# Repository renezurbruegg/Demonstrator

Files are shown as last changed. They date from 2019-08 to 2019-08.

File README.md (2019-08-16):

# PULPETUM MOBILE

## INSTALL INSTRUCTIONS
#### Set up Raspberry pi using NOOBS

Download NOOBS and boot Raspberry Pi

[Instructions](https://www.raspberrypi.org/downloads/noobs/)

Set up the operating system using Monitor and Keyboard. 

### Enable ssh
[See](https://www.raspberrypi.org/documentation/remote-access/ssh/)

#### Connect 
Get the Ip adress of the raspberry pi. Make sure the raspberry pi is in the same network as your computer
```bash
    ifconfig
```
Connect to the raspberry pi using ssh
 ```bash
    ssh pi@<your pi IP>
```
#### Enable I2c
```bash
    sudo raspi-config
```
#### install I2C utilities
```bash
    sudo apt-get install python-smbus i2c-tools
```

#### Restart Pi
```bash
    sudo reboot
```

#### `[ Optional `] Installing rmate for remote file editing
To edit files locally on your PC you need to set up rmate. 
Otherwise all editing of the files has to be done over ssh using console line editor like nano or vim.

1. Install rmate client on raspberry pi.
    ```bash
        pip install install rmate
    ```
2. Install an editor locally to edit the files. Must support the rmate plugin.
    e.g. Install [Visual Studio Code](https://code.visualstudio.com/download), install [Rmate Plugin](https://marketplace.visualstudio.com/items?itemName=rafaelmaiolla.remote-vscode), follow instruction from the plugin (https://medium.com/@prtdomingo/editing-files-in-your-linux-virtual-machine-made-a-lot-easier-with-remote-vscode-6bb98d0639a4) and start local server. 

3. Connect back to the Raspberry pi
    ```bash
        ssh -R 52698:127.0.0.1:52698 pi@<Raspberry Pi IP>
    ```
4. To edit e file remotely enter:
    ```bash
    rmate "yourFile.py"
    ```

#### Setting up the flask Backend Server
---

1.  Clone the repo 

    ```bash
    git clone --depth 1 https://gitlab.ethz.ch/zrene/pulp-demonstrator.git
    cd pulp-demonstrator
    ```

2.  Install the backend related requirements
    ```bash
    cd Server
    cd backend
    sudo pip install -r requirements.txt
    ```
#### Setting up the Angular Frontend Server
---
1.  Install frontend related dependencies

    -   Easiest way to handle node related dependencies is to install [nvm](https://github.com/creationix/nvm)
    -   Once you have node installed, install the project's dependencies

    ```bash
    cd ..
    cd front

    # install global dependencies
    npm install typescript -g

    # install project related dependencies
    npm install

    # run server
    ng serve --host 0.0.0.0
    ```

4.  Now navigate to `http://<Your RPI IP>:4200`

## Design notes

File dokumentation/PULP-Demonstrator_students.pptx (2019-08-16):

## PULP Demonstrator

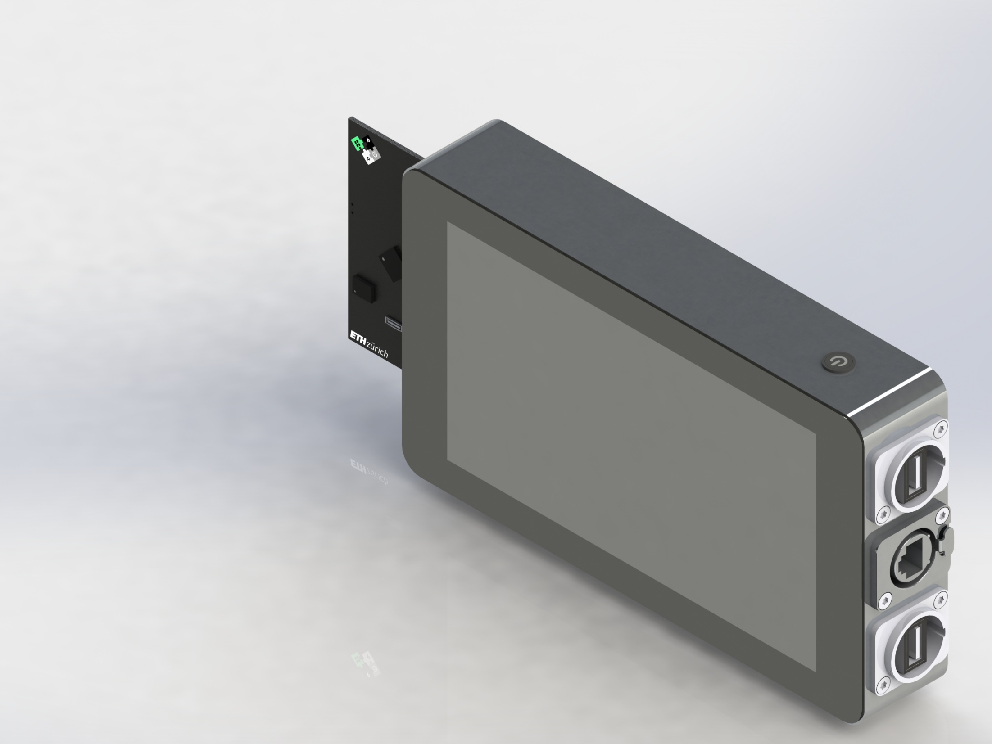
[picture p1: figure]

## PULP Demonstrator – Block Diagram

Philipp Mayer

Our ICs typically do not have a nonvolatile memory -> you have to supply them, flash your program and keep them supplied. To do so the connector needs the signal for a JTAG interface and in the housing must be space for this programmer + USB connection
https://www.olimex.com/Products/ARM/JTAG/ARM-USB-OCD-H/

## PULP Demonstrator – Block Diagram

Somewhere must be a button to turn off the whole thing

## PULP Demonstrator – Block Diagram

We need:
- USB to supply/charge the demonstrator
- A way to transfer easy data to and from the demonstrator (USB + Ethernet)
- Nice would be to design the housing in a way that Bluetooth and WiFi is still working

## PULP Demonstrator – Block Diagram

Connector selection:
- The connection to the daughter board must be mechanical stable
- Ideally it’s a common standard
- In the pin definition 1.) keep enough GND pins 2.) separate digital from analog 3.) keep unused pins for future usage

## Connector Selection

Ideal would be a widely used box connector with 2.54mm pitch (unfortunately a female solder connector is not easy to find):
https://www.te.com/deu-de/product-1-5103311-0.html (https://www.te.com/deu-de/product-1734099-6.html)
Alternative is something in this direction. Or direct in card format without (https://www.te.com/deu-de/product-1734099-6.html) connector on daughter board side
https://www.te.com/deu-de/product-1734099-6.html
https://www.te.com/deu-de/product-1734098-6.html

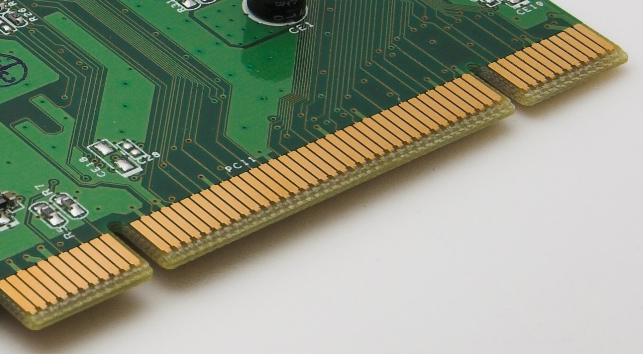
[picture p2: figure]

## PULP Demonstrator – Block Diagram

This connection must not be rigid. You can use cables to design a thinner device

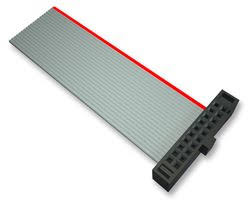
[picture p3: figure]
Bildergebnis für flachbandkabel

## PULP Demonstrator – Block Diagram

Building a PULP daughter board is not necessary part of your thesis. This we decide depending on your progress. However we need a way to test your HW and show the performance -> At least a simple daughter board with this banana/lab connecters should be made

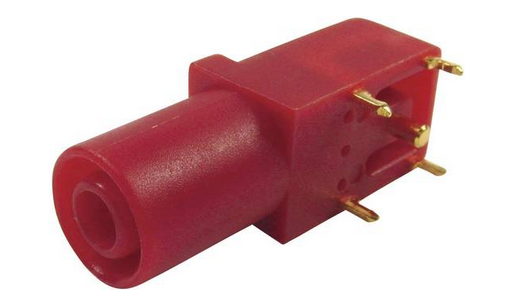
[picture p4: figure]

## Your PCB

The power supply is not simple as you need multiple voltage levels including a decoupled and stable supply for the analog measurement part.

Common practice is a switching regulator (efficiency) followed by a LDO (stability). If you read the documentation of the TI sample project you will find a good explanation.

There is also a charge pump to get a dual supply for the body biasing circuit

## Your PCB

Our ICs have typically a own supply for IOs. Never the less its not always 3.3V of the Rpi
-> all signals need level shifter.
The voltage level for the daughter board must come as input from the board

1.2 –> 3.3V

V(VGPIO)

3.3V

## Your PCB

The PCAL6416 has a I2C voltage and a IO voltage.
as the TPS62740 will have 5V input voltage also the control pins should have 5V levels

The same is valid for the I2C signals. Here you will need multiple pull-up resistors to the right voltage level

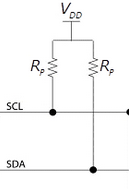
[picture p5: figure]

5V

3.3V

3.3V

V(VGPIO)

## Your PCB

I would recommend to take the analog input form this project:
TI Designs:TIDA-01012
Wireless IoT, Bluetooth® LowEnergy,4½ Digit,
100-kHzTrueRMSDigitalMultimeterReferenceDesign
It explains very nice the important parts, including design guide etc…
You will learn a lot by reading and partly replicating it.
(There are also more complex 24Bit examples but i think this will be sufficient)
There are two options:
a.) using a multiplexer to have different channels
b.) just build this part multiple times on your PCB
(The second will bring better results and is easier but will limit the number of channels )

## Which Component Packages?

It’s easy to design boards which are almost impossible to solder (especially without practice)
Depending on the availability (you will not get 100uF in a 0402 package) 0603 or 0402 is nice to solder -> we have also most resistors here
For ICs the best compromise between parasitics, soldering and size is QFN
-> I try to avoid packages with legs (however for opamps etc. this is not always possible. Its also a matter of taste.
-> We can solder BGAs, but typically they make the PCB more expensive (more layers lower pitch)

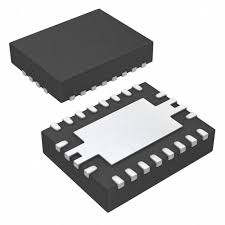
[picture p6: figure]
Bildergebnis für QFN
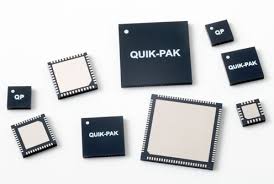
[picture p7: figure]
Bildergebnis für QFN
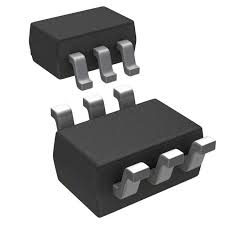
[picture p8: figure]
Bildergebnis für sc70
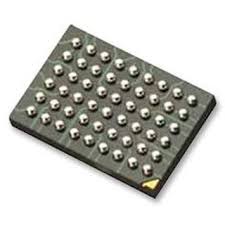
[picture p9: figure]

## Software design

1.) setup linux
2.) play with kivy (if you don’t find a better alternative)
3.) connect a LTC2631(on a breakout board) and write the I2C driver
3.) if it is possible to the same for the other I2C ICs
4.) write the driver to SPI ADC
5.) make a fully working demo
- Find a user-friendly way to configure the voltages
- It should be a demonstrator -> the configuration must be somehow password controlled
- Find ways to visualize your data
6.) If the basics work perfect think about how to support different daughter boards. How configurations can be stored. How new GUIs can be implemented
7.) The ultimate application for now is to get a video stream via SPI. Would you be able to read this data and show it on the LCD?

SW design should be independent from the HW design process!

## Mechanical design

-> be aware that the workshop will need time
1.) think about the best suited way to fit everything inside.
2.) find connectors, buttons etc. How can be everything accessible without big afford.
4.) Define together with HW board size, connector type, and connector position.
5.) Design a case under consideration of all information. Draw all important parts. (for most connectors etc. 3D files will be available. In Altium you can make a quick export without having the layout finished)
6.) During the drawing think about how the machine will manufacture it. Not everything is possible (min radii, machining direction, complexity of your design.. )
7.) Meeting with the workshop -> (adaption?) -> 3D printing
8.) if everything is perfect manufacturing in alu.

Case design should be as much independent as possible from the HW

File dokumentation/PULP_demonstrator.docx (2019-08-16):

# 1 Connectors

## 1.1 Sense & Supply Module <-> Raspberry Pi 3

Sense & Supply Module ist am auf der linken Seite des Gehäuses und der Rasperry Pi auf der rechten Seite (direkter Anschluss für USB, Ethernet). Beide Boards warden durch ein 40 Pin Flachbandkabel verbunden. (Achtung 50pin stecker) https://www.te.com/deu-de/product-1-5103311-0.html

https://www.raspberrypi.org/documentation/usage/gpio/README.md

Pinseite Bohrloch

1 | 3.3V | 5V | 2
3 | GPIO2 (Data) | 5V | 4
5 | GPIO3 (Clock) | GND | 6
7 | GPIO4 | GPIO14 (TX) | 8
9 | GND | GPIO15 (RX) | 10
11 | GPIO17 | GPIO18 | 12
13 | GPIO27 | GND | 14
15 | GPIO22 | GPIO23 | 16
17 | 3.3V | GPIO24 | 18
19 | GPIO10 (MOSI) | GND | 20
21 | GPIO9 (MISO) | GPIO25 | 22
23 | GPIO11 (SCLK) | GPIO8 (CE0) | 24
25 | GND | GPIO7 (CE1) | 26
27 | ID EEPROM | ID EEPROM | 28
29 | GPIO5 | GND | 30
31 | GPIO6 | GPIO12 | 32
33 | GPIO13 | GND | 34
35 | GPIO19 | GPIO16 | 36
37 | GPIO26 | GPIO20 | 38
39 | GND | GPIO21 | 40

## 1.2 PULP module <-> Sense & Supply Module

Auf der linken Seite einfach einstecken.

1. Leiterplatte-an-Leiterplatte

https://www.te.com/deu-de/product-1734099-6.html

Stabil genug?

2. Header Stecker wie bei Rasperry Pi

Stiftleiste gewinkelt am Sense & Supply Module

Buchse am PULP Module

## 1.3 ON/OFF <-> PiJuice HAT

Wie stellt man den PiJuice HAT ab?

## 1.4 PiJuice HAT <-> Raspberry Pi 3 <-> Touchscreen

Vorgegebene Stecker

## 1.5 JTAG??

USB -> USB-OCD -> Sense Module

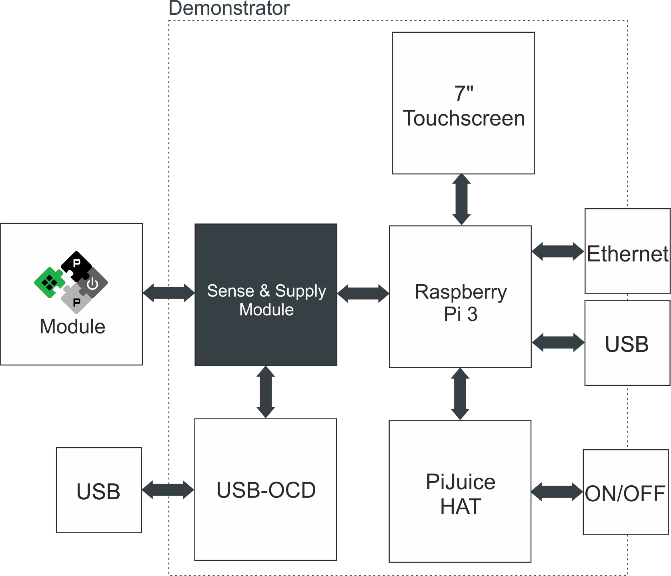
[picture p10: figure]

Fig. 1 Block diagram PULP demonstrator

# 2 Sense & Supply Module

## 2.1 Pinbelegung Stecker zu Rasperry Pi

1 | 3.3V | 5V | 2
3 | SDA | 5V | 4
5 | SCL | GND | 6
7 | GPIO4 | GPIO14 (TX) | 8
9 | GND | GPIO15 (RX) | 10
11 | GPIO17 | GPIO18 | 12
13 | GPIO27 | GND | 14
15 | GPIO22 | GPIO23 | 16
17 | 3.3V | GPIO24 | 18
19 | MOSI | GND | 20
21 | MISO | GPIO25 | 22
23 | SCLK | CE0 | 24
25 | GND | CE1 | 26
27 | NC | NC | 28
29 | GPIO5 | GND | 30
31 | GPIO6 | GPIO12 | 32
33 | GPIO13 | GND | 34
35 | GPIO19 | GPIO16 | 36
37 | GPIO26 | GPIO20 | 38
39 | GND | GPIO21 | 40

I2C

JTAG?

## 2.2 Pinbelegung Stecker zu PULPModule

Versorgungsspannungen: Obere Pins

Spannungsmessung, Strommessungen: mittlere Pins

JTAG, ID: untere Pins

Weshalb MUX bei I2C? → replace mux with bidirectional i2c level shifter such as PCA9306, allows to use pulp or rpi as a master…. Good job, Philipp

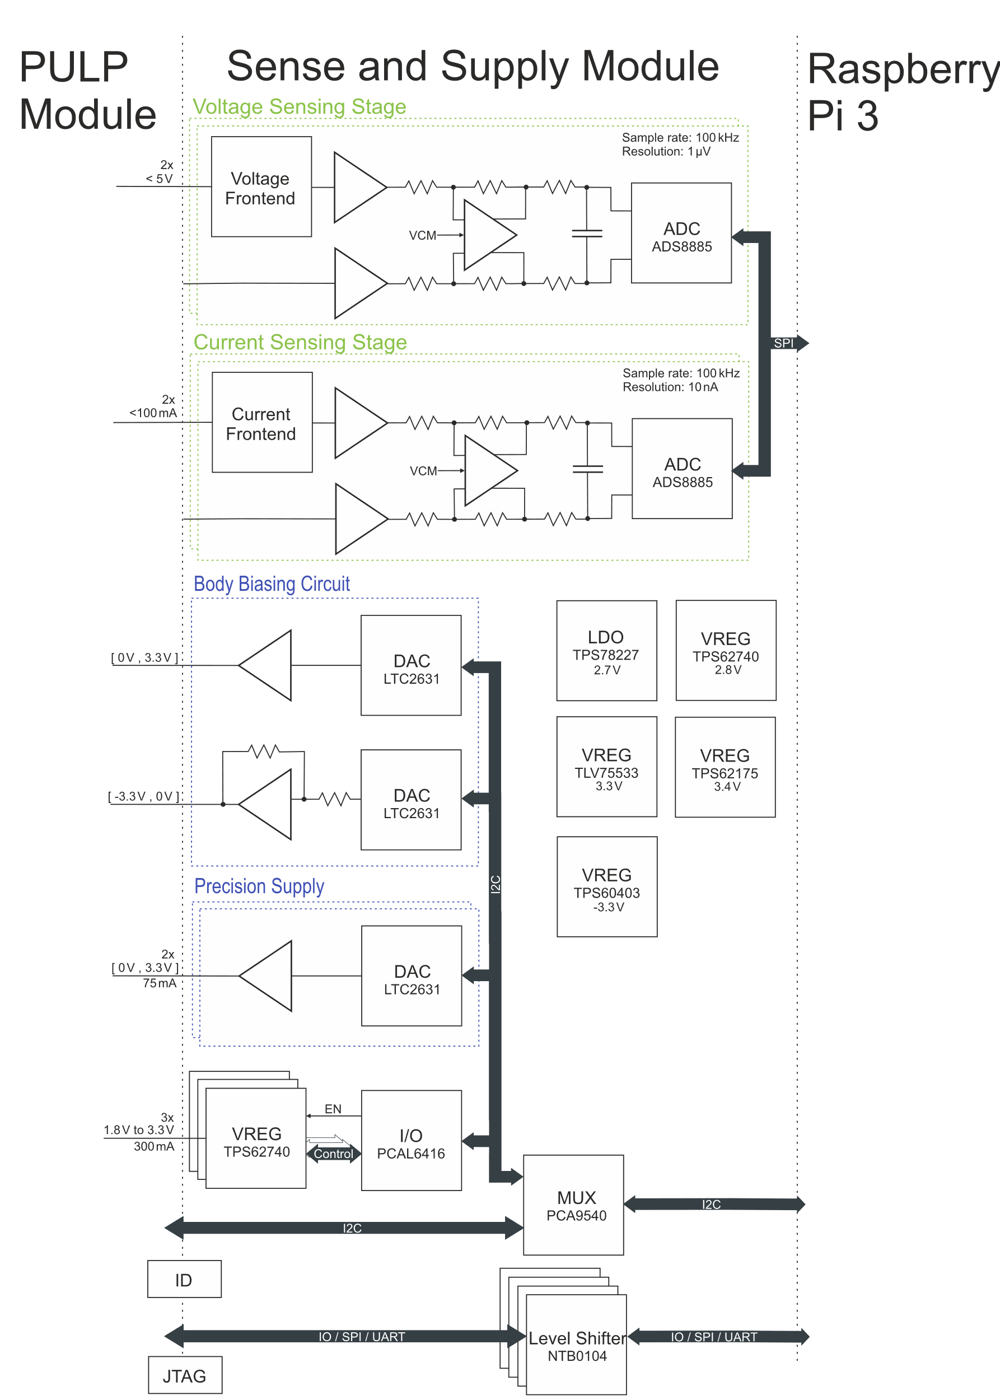
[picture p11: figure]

Fig. 2 Block diagram Sense and Supply module.

# 1 Voltage Front End

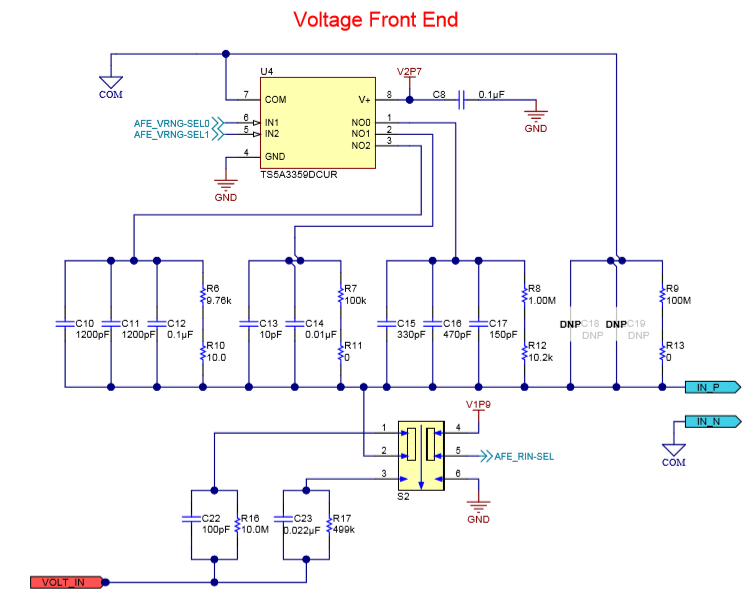
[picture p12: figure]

Beim TIDA-01012 kann man zwischen vier verschiedenen Ranges auswaehlen: 50V, 5V, 500mV und 50mV. Mit dem TS5A3359 wird die Range eingestellt.

VOLT_IN wird mit einem Spannungsteiler skaliert, sodass IN_P auf ca. 50mV ist. Fuer 50mV wird der Strang mit 100MOhm gewaehlt. Fuer 500mV die Straenge mit 100MOhm und 1.0102MOhm in parallel.

Die 50mV werden mit dem fullz differential amplifier THS4531 um 44.2 verstaerkt. So wird die Referenzspannung des ADC 50mV*44.2 ~= 2.2V erreicht.

# 1 ADC

## 1.1 Anti aliasing filter

# 3 LTC2631

FSE

Symbol | Parameter | Conditions | LTC2631-12
| | | MIN | TYP | MAX | UNITS
FSE | Full-Scale Error | Vcc=3V, Internal Ref. (Note 14) | | +- 0.08 | +-0.4 | %FSR

Note 14: Full-scale error is determined using the reference voltage measured at the REF pin.

Similarly, limiting can occur near full-scale when the REF pin is tied to VCC. If VREF = VCC and the DAC full-scale error (FSE) is positive, the output for the highest codes limits at VCC, as shown in Figure 5c. No full-scale limiting can occur if VREF is less than VCC – FSE.

# 1 ADS8885

## 1.1 Digital Interface

The ADS8885 can work either in a 3- or 4-wire interface. There is a busy indicator which allows the ADS8885 to indicate a new datatransmition.

## 1.2 4-Wire CS Mode Without a Busy Indicator

As the datasheet says: This interface option is useful when one or more ADCs are connected to an SPI-compatible digital host.

# 1 Raspberrry Pi

## 1.1 SPI

There are multiple chips connected as slaves to the master. To provide proper data transmission one has to select the appropriate chip. This can be done by the Pins CE0 and CE1. Unfortunately, there are more then to SPI slaves to select therefore GPIO Pins will be used to select the appropriate chip by setting the Pin to low before doing the transmittion.

# 2 References

Datasheet ADS8885 05.03.2019 http://www.ti.com/lit/ds/symlink/ads8885.pdf

SPI Docum Raspberry PI 05.03.2019 https://www.raspberrypi.org/documentation/hardware/raspberrypi/spi/README.md

LTC2631CTS8-LZ12#TRMPBF

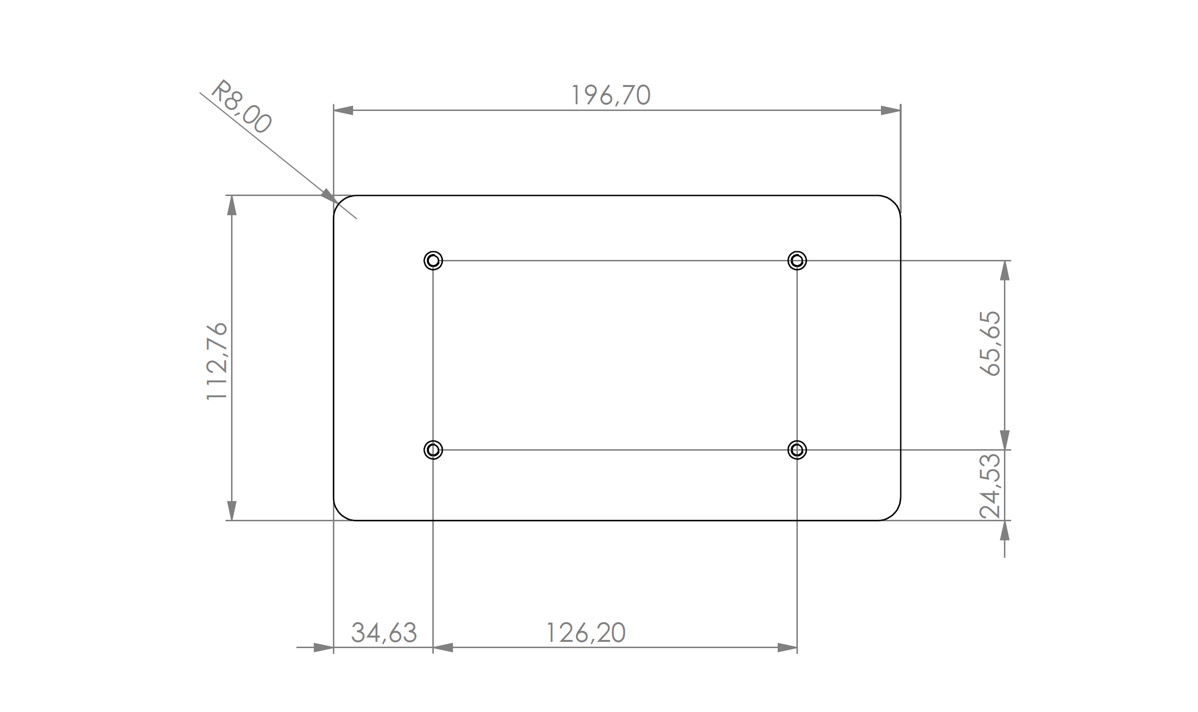
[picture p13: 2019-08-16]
3D Modelle/Case/Mechanical Drawings/MechanicalDrawing3.PNG

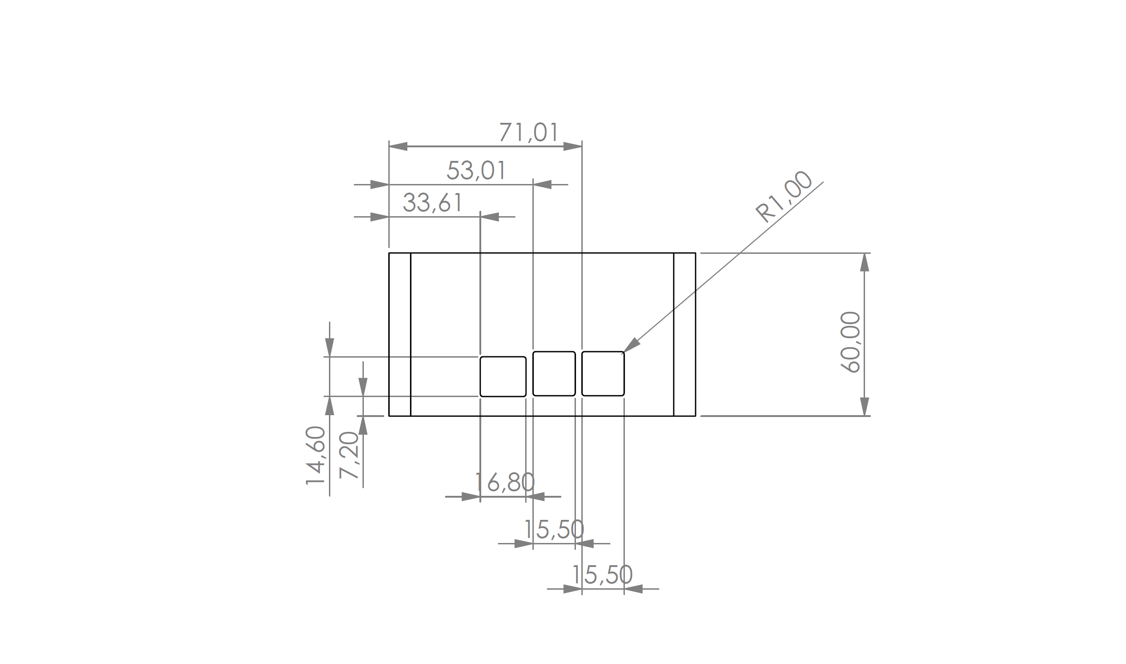
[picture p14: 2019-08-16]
3D Modelle/Case/Mechanical Drawings/MechanicalDrawing4.PNG

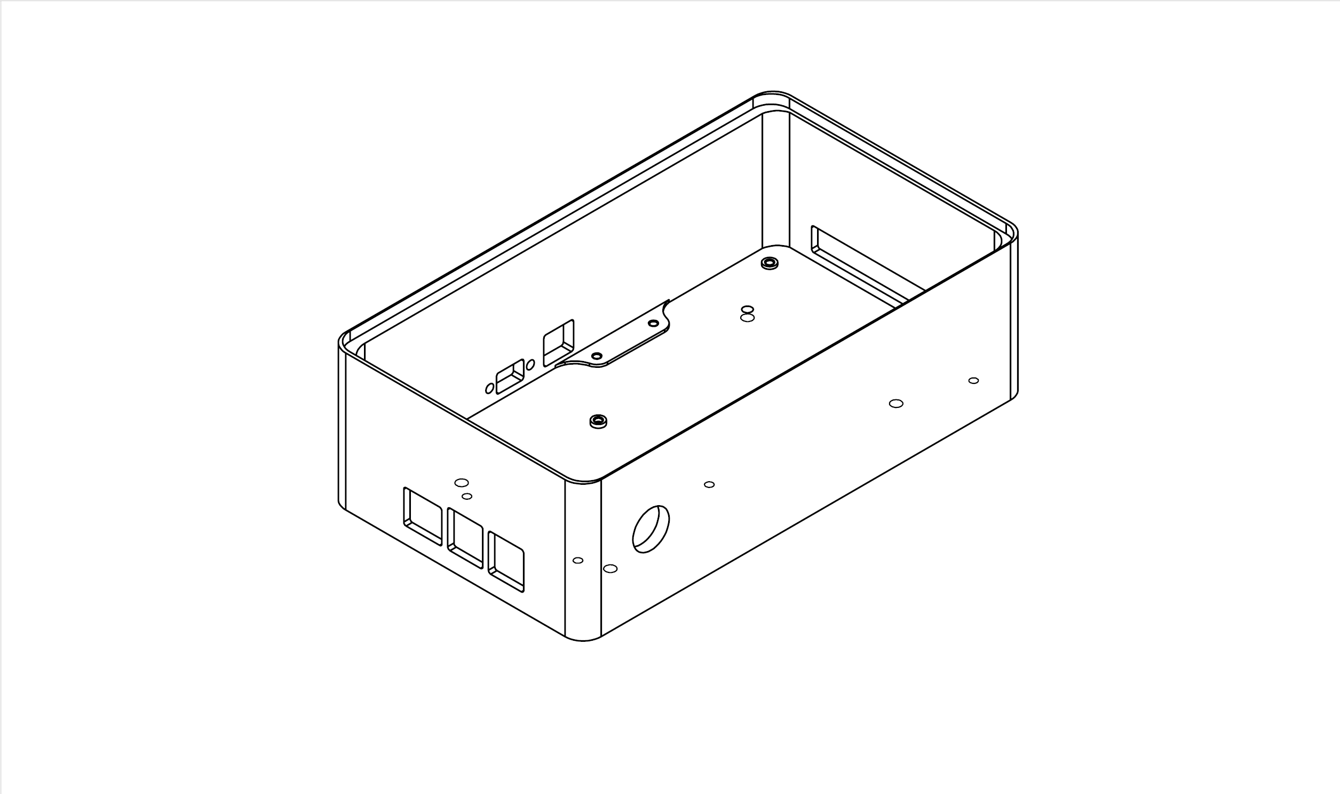
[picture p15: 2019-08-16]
3D Modelle/Case/Mechanical Drawings/Mechanical Drawing 11.PNG

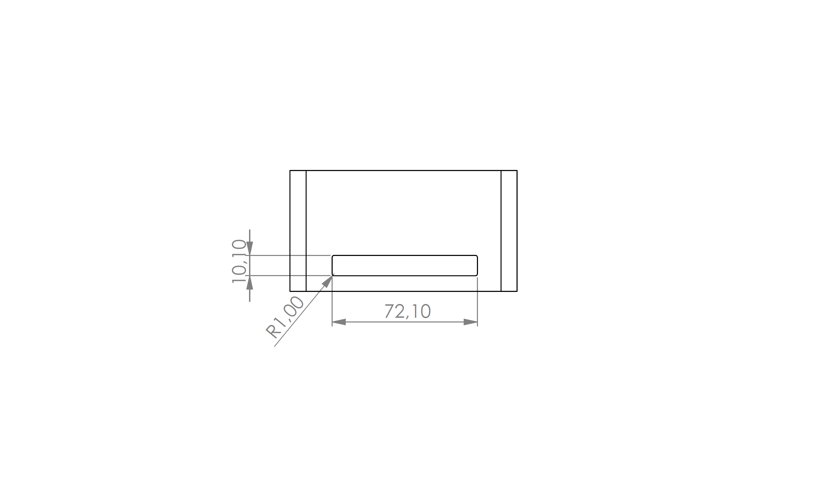
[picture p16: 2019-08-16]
3D Modelle/Case/Mechanical Drawings/MechanicalDrawing6.PNG

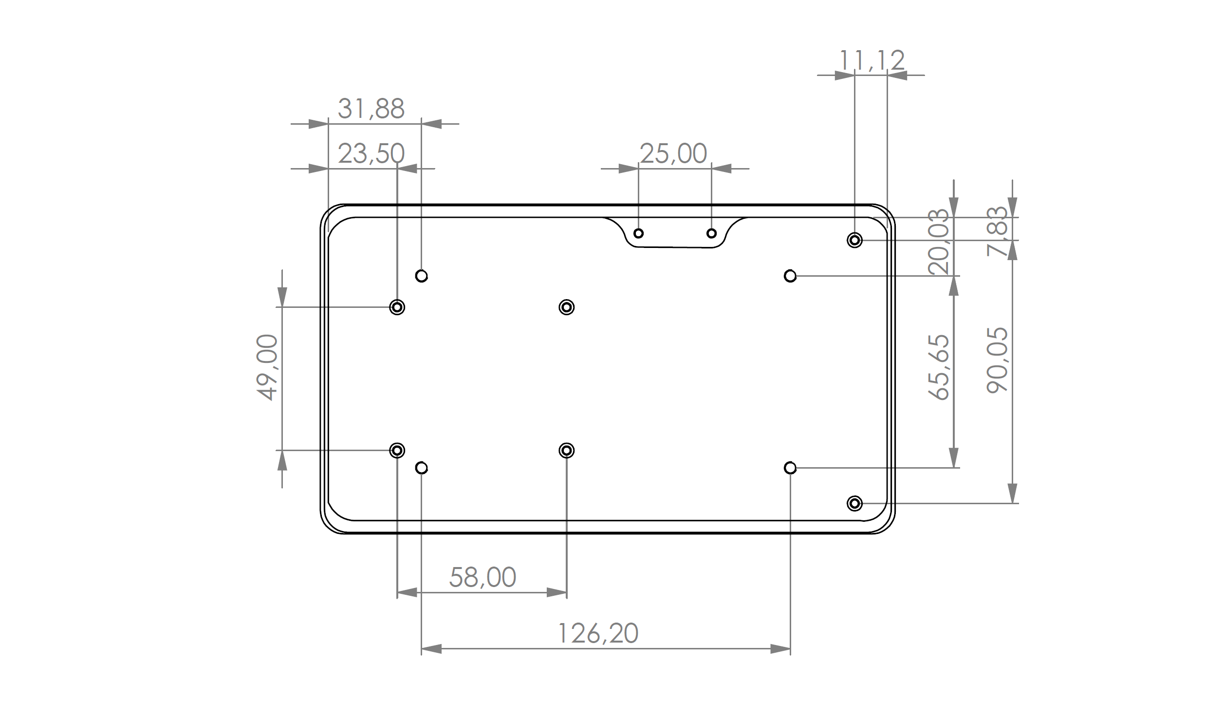
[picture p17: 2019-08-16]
3D Modelle/Case/Mechanical Drawings/Mechanical Drawing 1.PNG

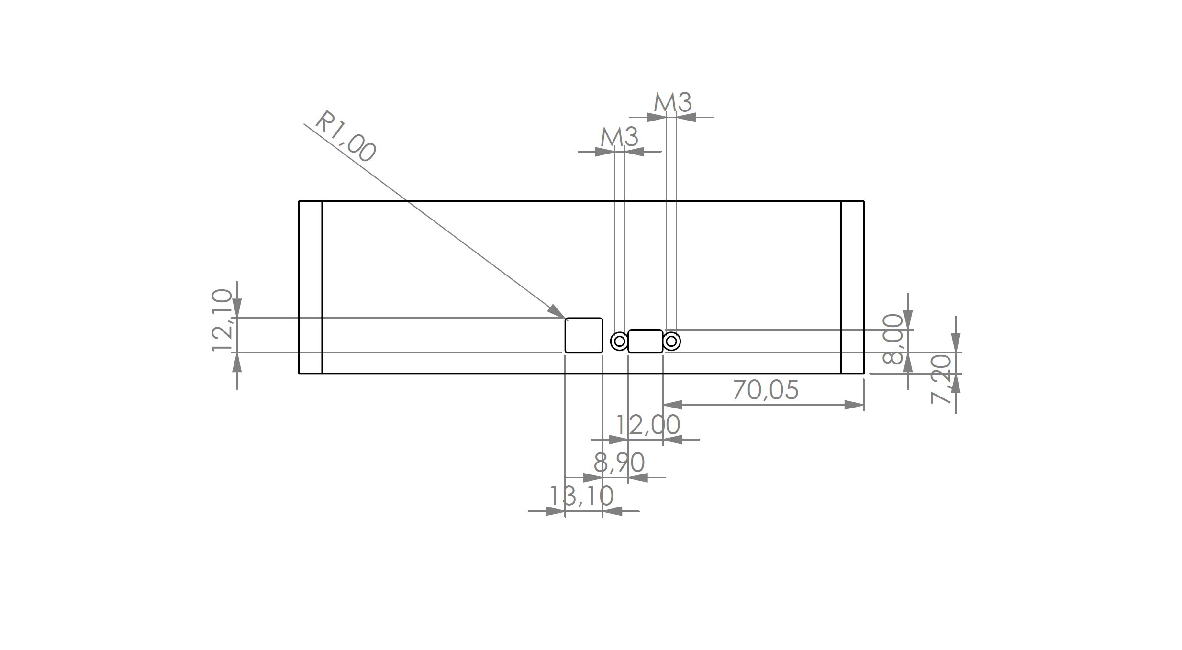
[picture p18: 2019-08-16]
3D Modelle/Case/Mechanical Drawings/MechanicalDrawing7.PNG

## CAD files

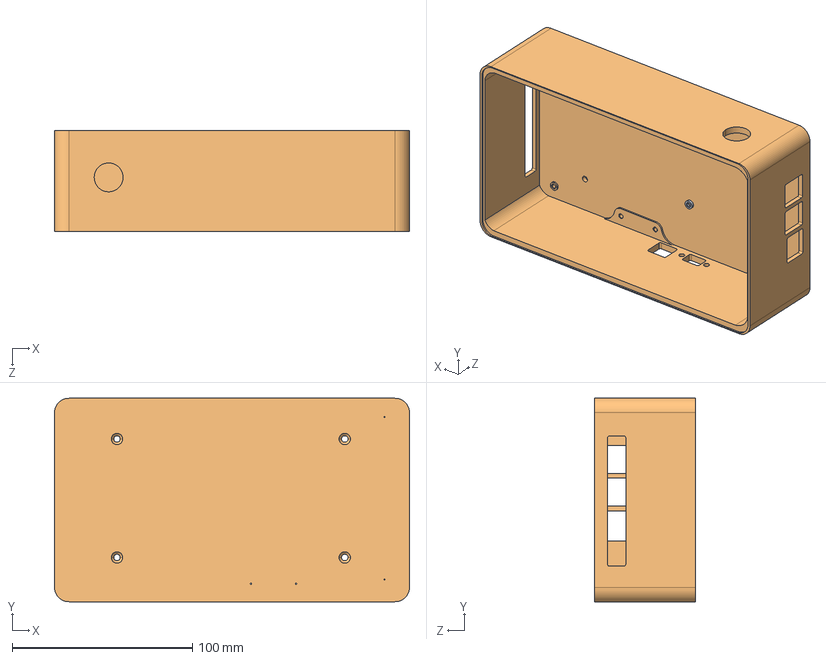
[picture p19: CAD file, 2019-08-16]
3D Modelle/Case/Case Pulp Demonstrator.STEP
196.7 x 112.8 x 56.0 mm

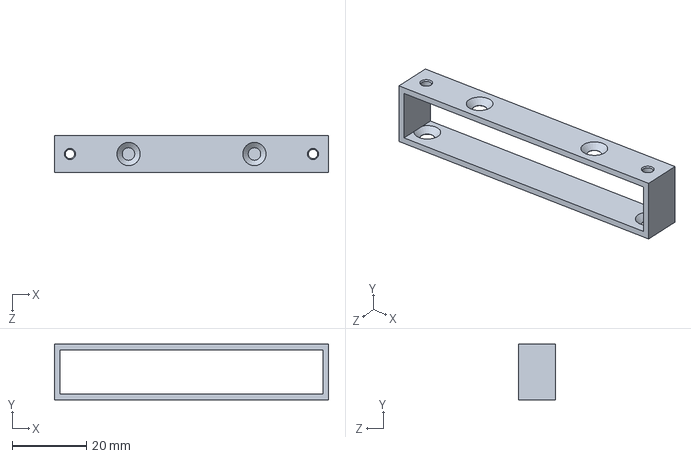
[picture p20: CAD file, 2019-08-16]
3D Modelle/Mount/Halterung A.SLDPRT
74.0 x 15.0 x 10.0 mm

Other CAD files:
3D Modelle/Mount/Halterung B.SLDPRT
3D Modelle/Case/Case Pulp Demonstrator.SLDPRT
3D Modelle/Case/Case Pulp Demonstrator.STL
3D Modelle/Mount/Halterung A.SLDDRW
3D Modelle/Mount/Halterung A.STL
3D Modelle/Mount/Halterung B.SLDDRW
3D Modelle/Mount/Halterung B.STL

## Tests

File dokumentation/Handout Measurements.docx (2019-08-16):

Handout Measurements

Couple different plots to characterize the Demonstrator

Autoren:

Jonas Künzli

Marina Homs

Rene Zurbrügg

June 2019

# 1 Calibration

## 1.1 Voltage

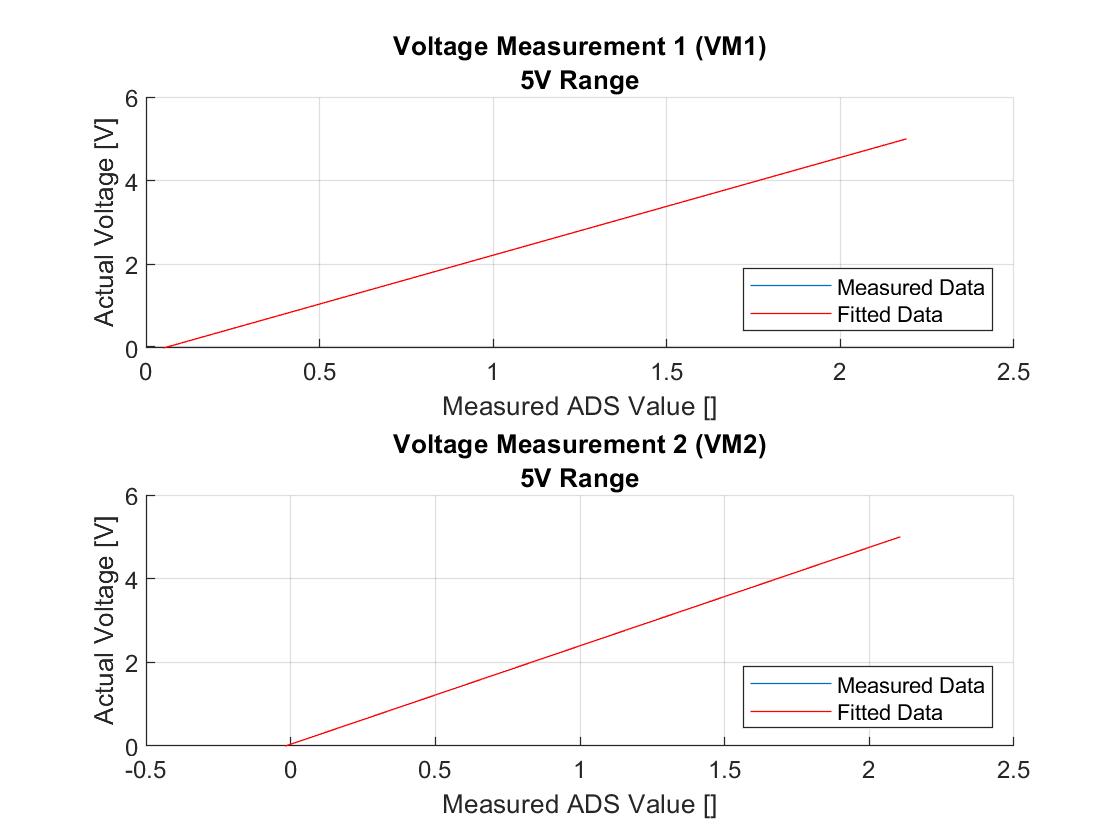
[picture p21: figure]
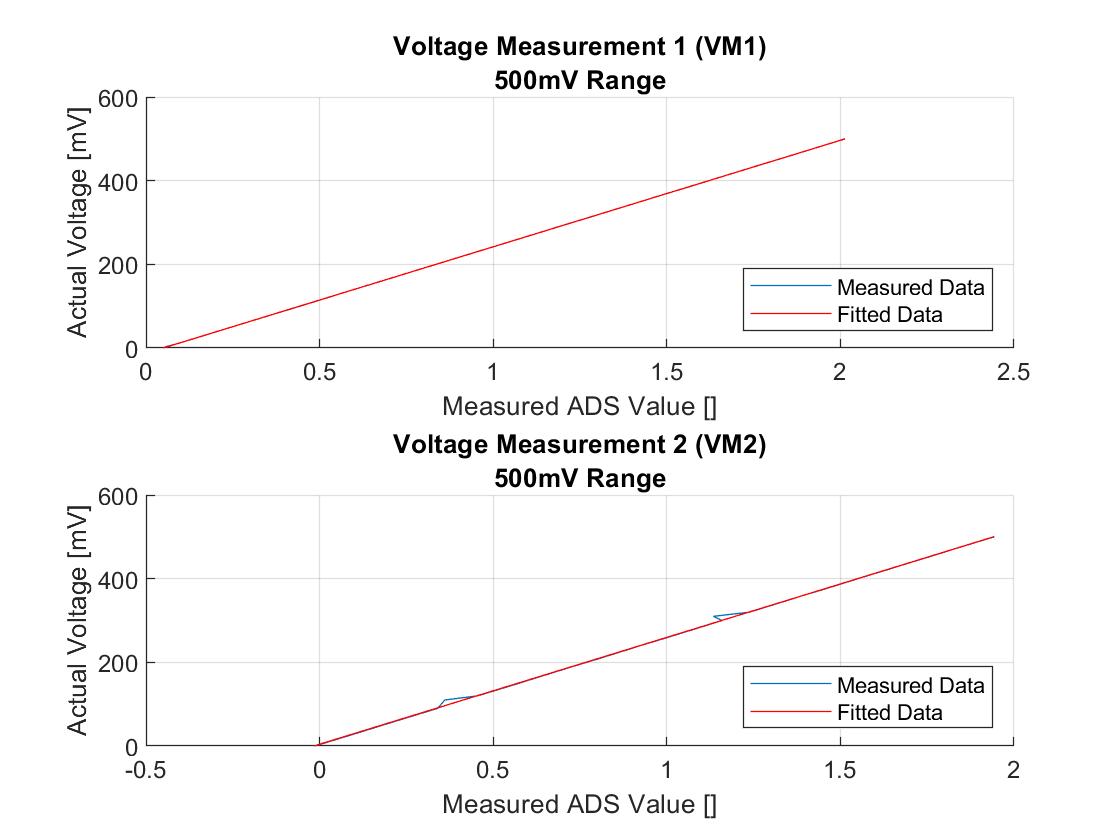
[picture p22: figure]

## 1.2 Current

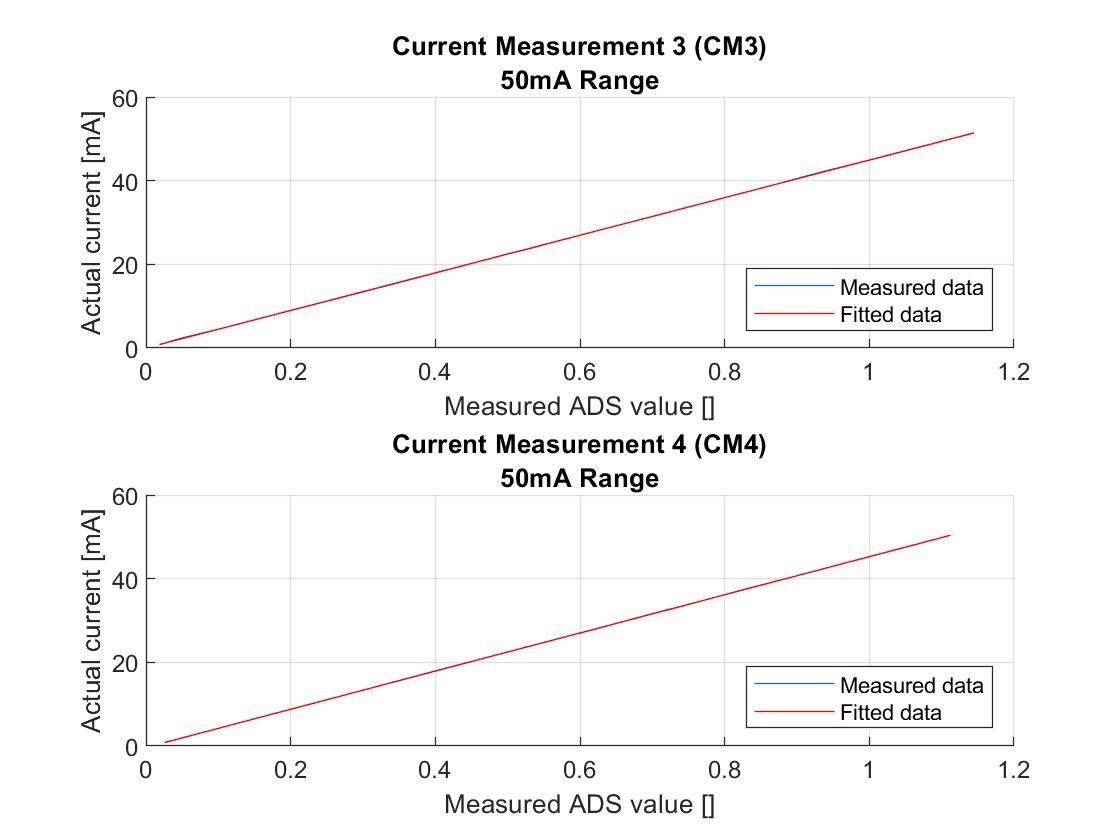
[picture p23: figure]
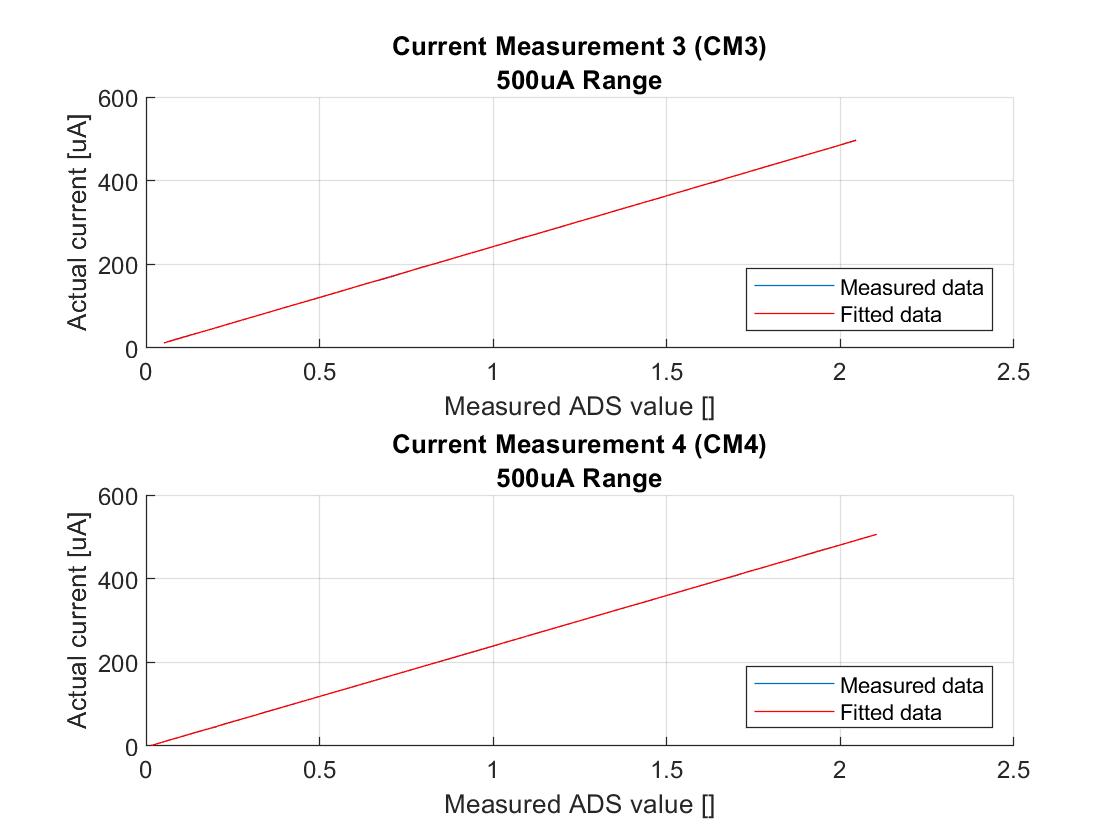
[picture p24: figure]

# 2 Output Current vs. Output Voltage

## 2.1 Precision Supply

## 2.2 Variable Supply

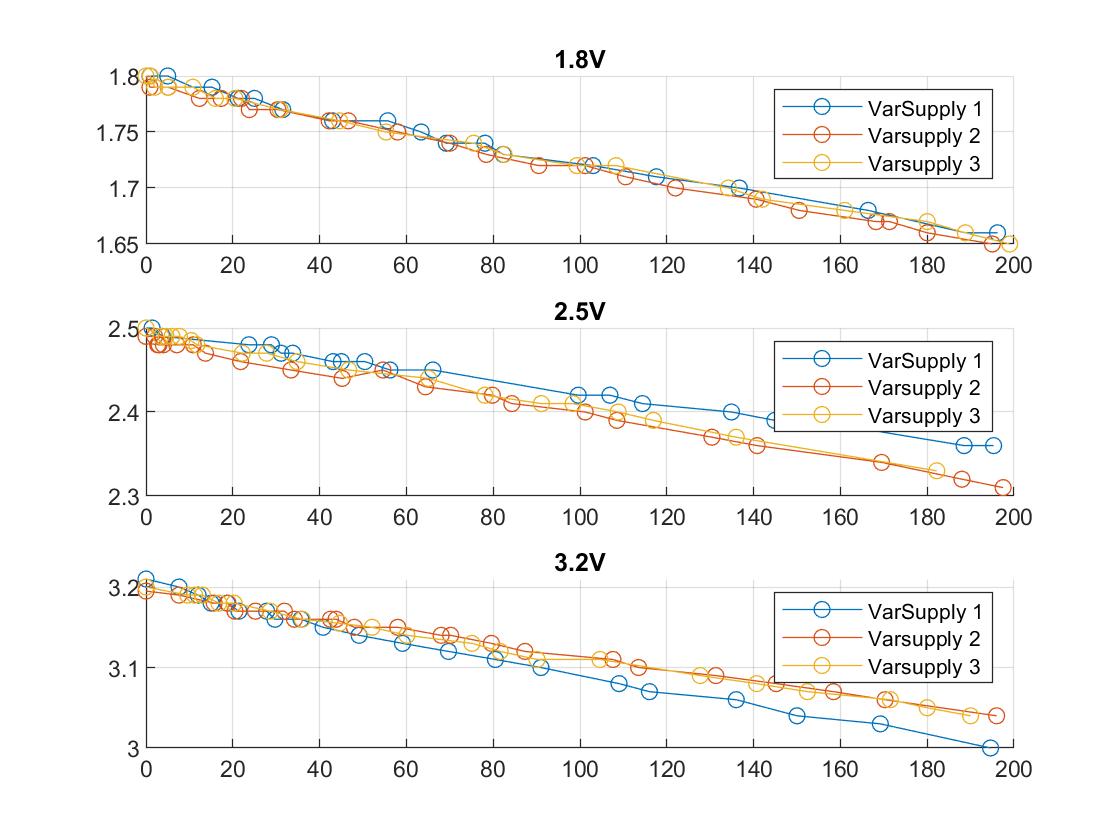
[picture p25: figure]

## 2.3 Body Bias

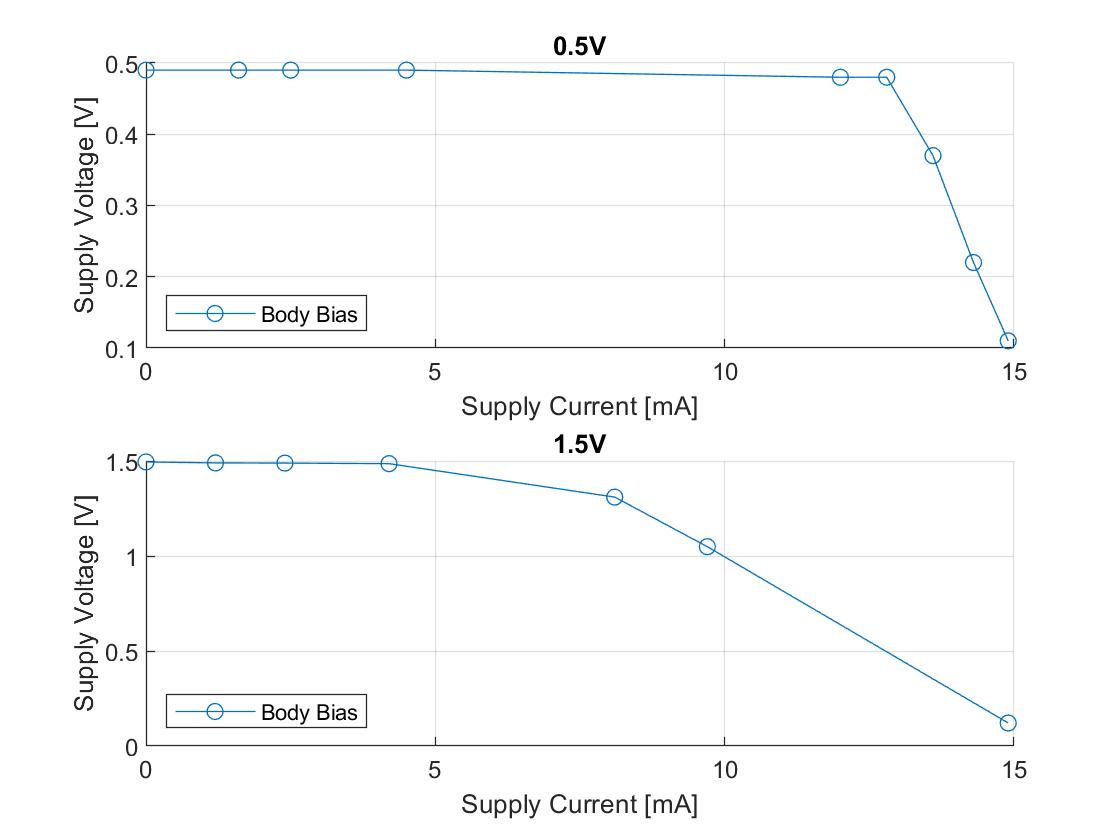
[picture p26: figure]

# 3 Load Response

## 3.1 Precision Supply 1

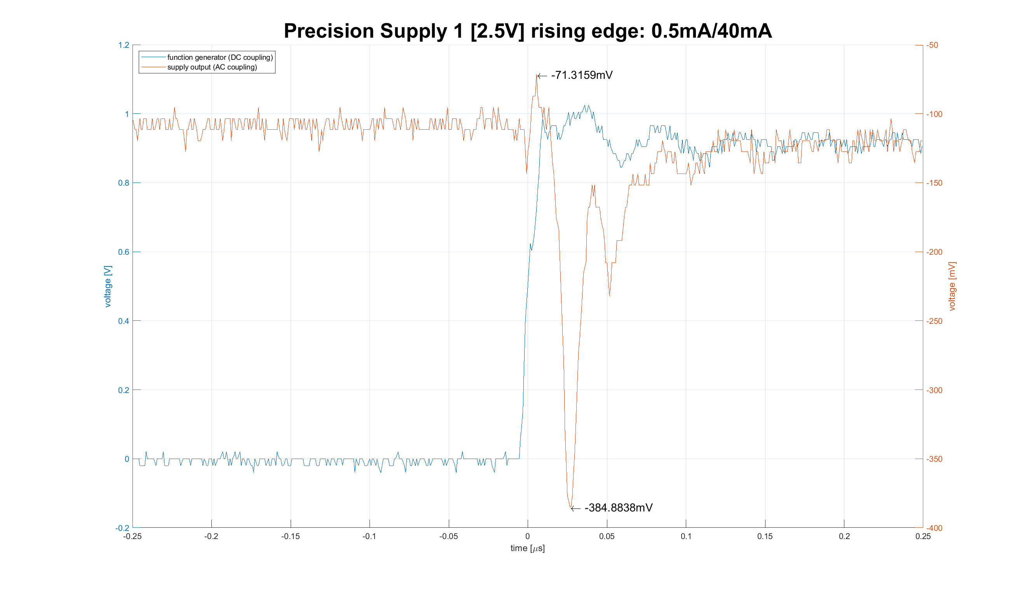
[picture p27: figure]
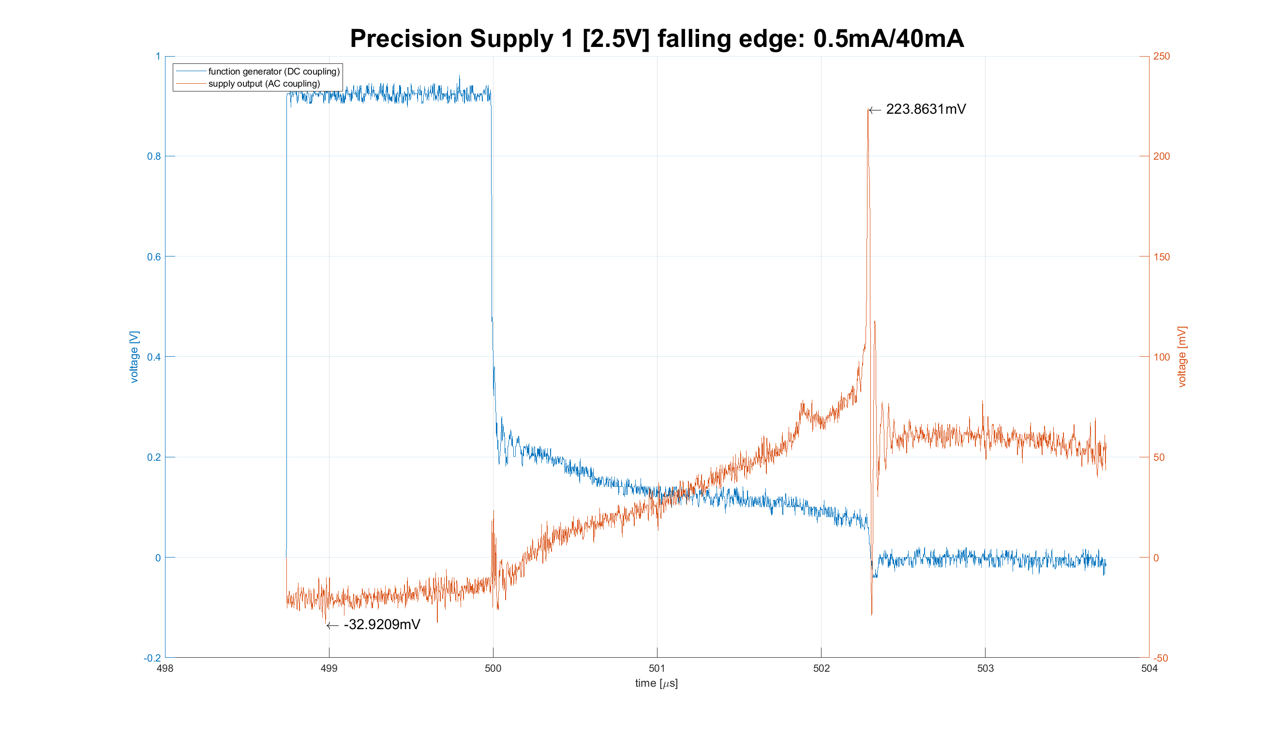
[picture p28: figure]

## 3.2 Precision Supply 2

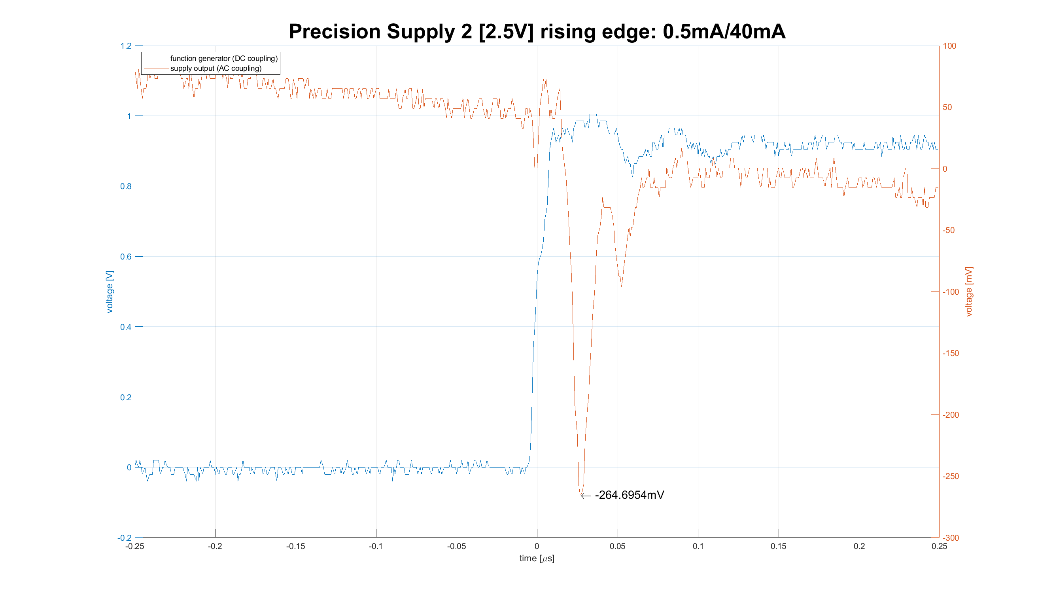
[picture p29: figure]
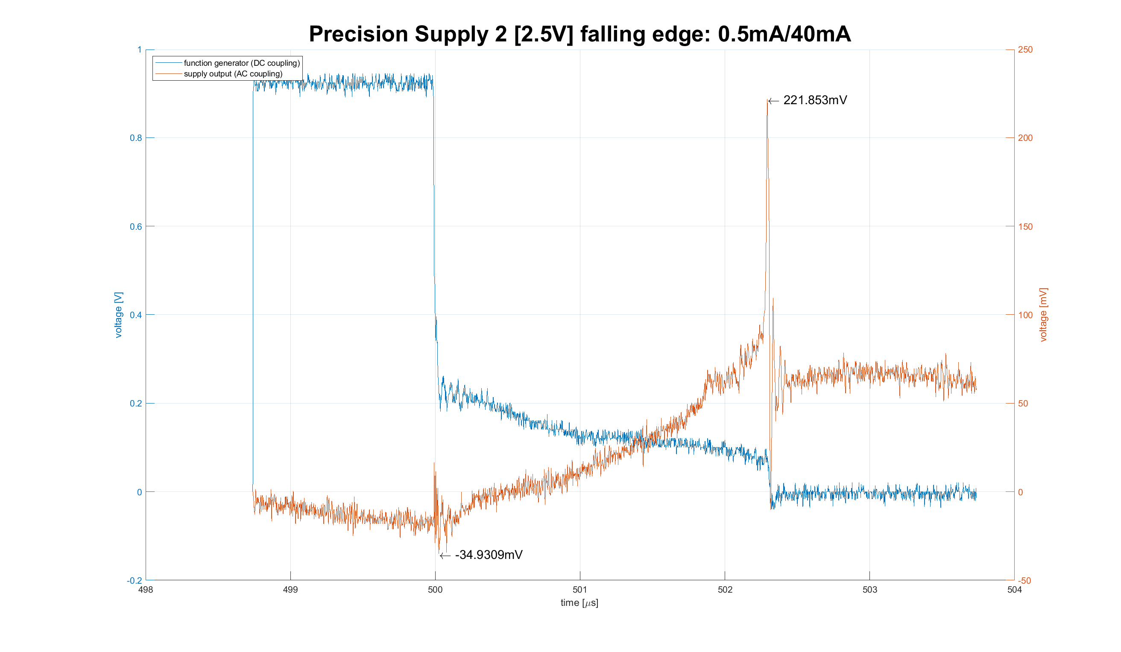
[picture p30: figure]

## 3.3 Variable Supply 1


## 3.4 Variable Supply 2


## 3.5 Variable Supply 3


# 4 Measurements

## 4.1 Voltage

### 4.1.1 VM 1


### 4.1.2 VM 2


## 4.2 Current

### 4.2.1 CM 3


### 4.2.2 CM 4


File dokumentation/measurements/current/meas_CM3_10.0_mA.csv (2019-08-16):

cm3
10.296969880501408
10.315827221179362
10.293541273105417
10.37668500245821
10.296969880501408
10.320970132273349
10.387827976495183
10.333827410008317
10.261826654692495
10.222397669638594
10.293541273105417
10.258398047296504
10.29182696940742
10.290969817558423
10.333827410008317
10.302969943444394
10.278969691672453
10.241255010316547
10.272969628729468
10.308970006387378
10.306398550840385
10.305541398991387
10.298684184199404
10.254112288051514
10.217254758544605
10.270398173182475
10.29182696940742
10.290969817558423
10.265255262088488
10.266969565786482
10.271255325031472
10.268683869484478
10.34411323219629
10.331255954461323
10.290969817558423
10.386113672797187
10.303827095293391
10.325255891518339
10.266112413937485
10.264398110239489
10.25582659174951
10.299541336048401
10.338113169253306
10.20782608820563
10.272969628729468
10.270398173182475
10.296969880501408
10.260969502843498
10.24811222510853
10.280683995370449
10.24382646586354
10.271255325031472
10.259255199145501
10.341541776649297
10.263540958390491
10.27211247688047
10.29182696940742
10.285826906464436
10.302112791595395
10.313255765632368
10.279826843521452
10.270398173182475
10.296969880501408
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

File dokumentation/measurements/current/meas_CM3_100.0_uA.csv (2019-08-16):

cm3
97.83733094292407
98.72698201753249
98.75015001426708
101.8268599806212
97.0820542493763
97.97633892333164
101.00207929686964
100.80746812429905
101.89173037147806
100.11706182160815
99.32471633328502
99.0513339718168
100.98354489948197
100.07072582813895
96.31287675778778
99.86684745687452
98.83355480251163
98.96329558422535
100.82600252168672
98.79648600773628
99.53786190324328
99.26447954177507
100.21436740789343
99.00963157769453
99.17644115418362
100.27460419940338
98.00877411876007
100.26533700070955
98.14314849982071
99.22741074699972
97.33690221345684
97.19789423304927
97.87903333704634
97.73075815794493
99.86684745687452
101.02988089295116
97.09595504741705
98.89379159402156
101.51640882437763
100.48774976936166
101.78052398715201
102.22998312380314
96.16923517803329
98.5092028482273
100.08462662617971
100.83990331972748
102.08170794470173
101.30326325441936
99.59809869475323
100.99744569752272
99.41275472087648
99.39885392283573
101.29399605572553
100.70552893866683
99.52859470454945
98.55090524234957
100.23753540462803
98.49066845083962
97.45274219712981
100.28850499744414
98.86598999794005
99.07913556789832
101.36813364527623
97.95317092659704
97.55468138276203
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

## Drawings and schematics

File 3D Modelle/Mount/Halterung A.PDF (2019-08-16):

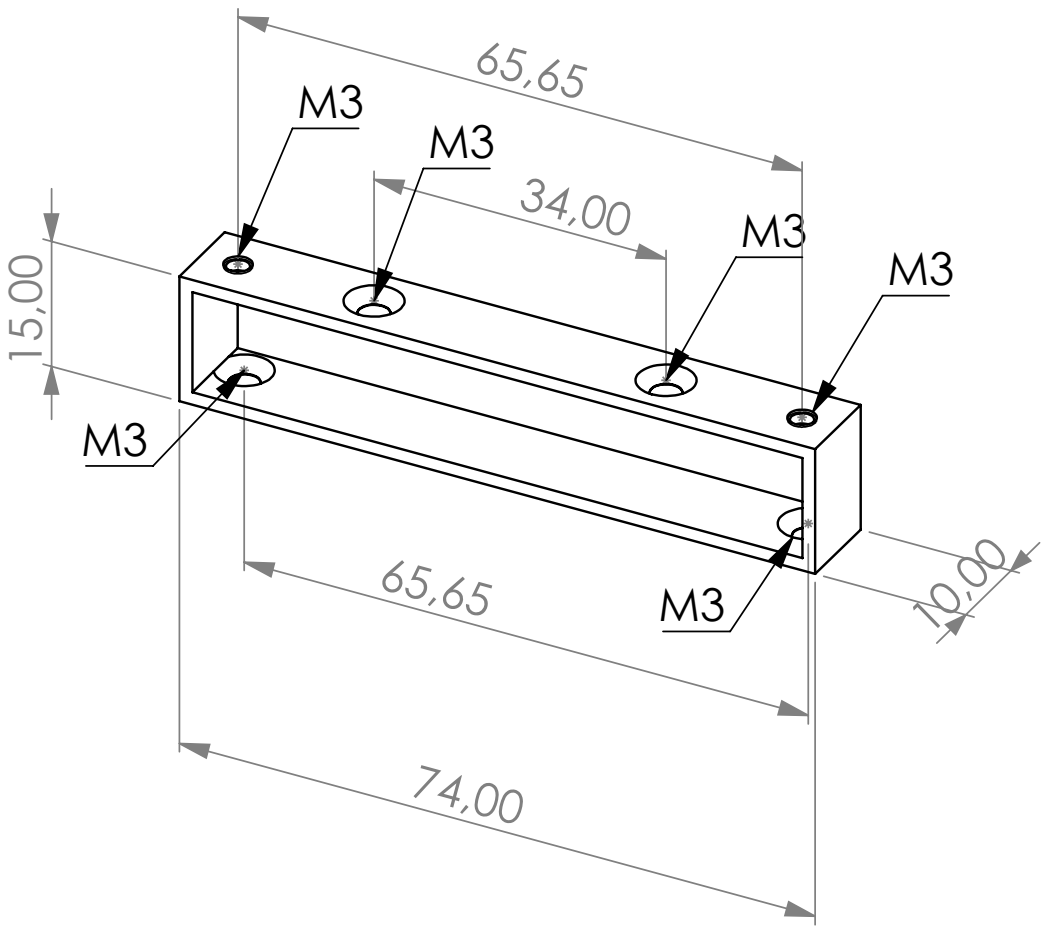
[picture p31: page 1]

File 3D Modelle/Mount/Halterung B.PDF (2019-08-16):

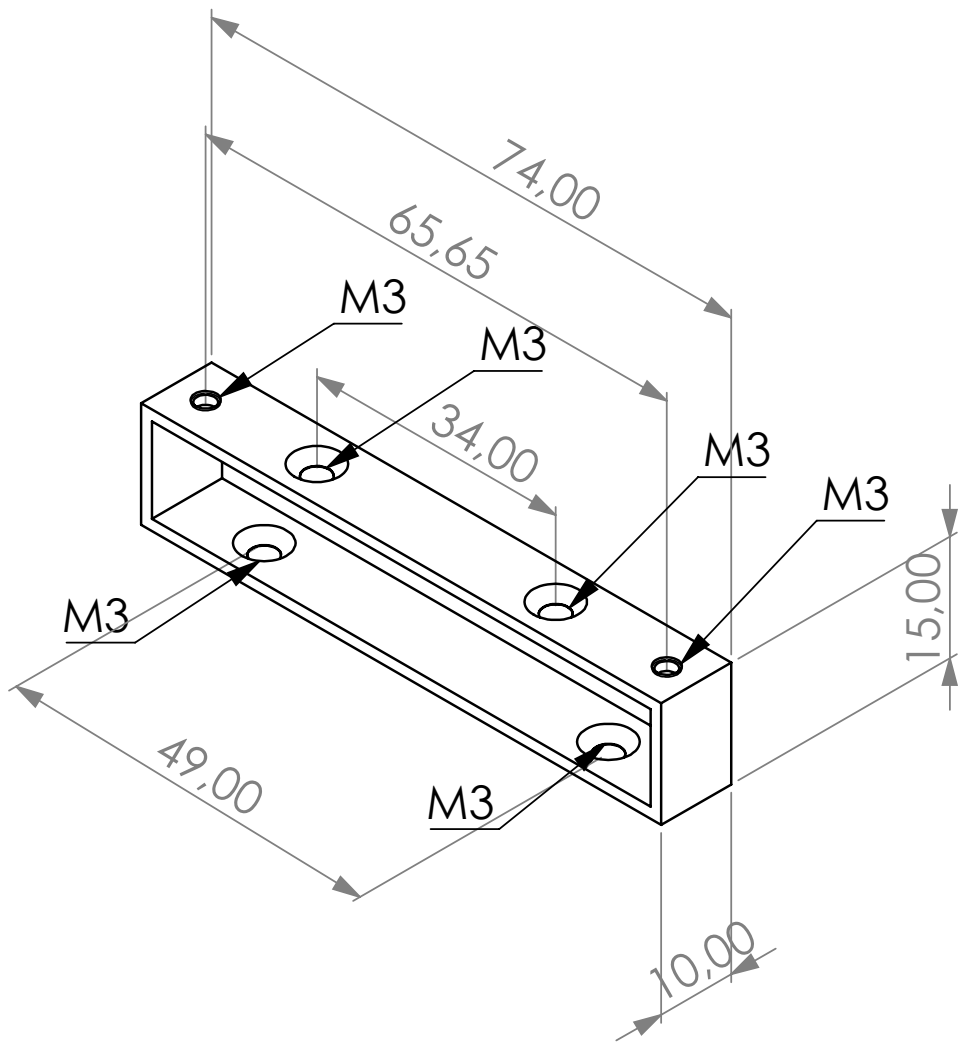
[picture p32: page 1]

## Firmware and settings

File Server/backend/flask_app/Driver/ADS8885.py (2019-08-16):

""" Driver for the ADS8885 chip """
import logging

logger = logging.getLogger(__name__)

try:
    import smbus
except ImportError:
    def _getBus(self, num):
        return self
    def read_word_data(self, adress, cmd):
        logger.debug("Mock Object -- read word data: addrress" + str(adress) + " cmd: " + str(cmd))
        return 0
    def write_word_data(self, device_address, mode, value):
        logger.debug("Sendind word data emulation: to: " + str(device_address) + " mode: " + str(mode)  + " value: " + str(value));

    obj = type('',(object,),{'read_word_data':read_word_data,'SMBus':_getBus,'write_word_data':write_word_data})()
    smbus = obj
try:
    import spidev
    simul = False
except ImportError:
    simul = True
    logger.error("could not import spidev")
try:
    import RPi.GPIO as GPIO
except ImportError:
    simul = True
    logger.error("could not import GPIO")
# from .PCAL6416 import PCAL6416
# from .PCAL6416 import PinAssignment

import random

SPI_MOSI = 10
SPI_MISO = 9
SPI_CLK = 11


class ResolutionScaler:
    """ Class that offers a simple transform function. <br>
        Used to alibrate a ADS8885 chip. <br>
        The getScaledValue returns the real applied value before the voltage devider for a measured Value of the ADS chip.
    """
    def __init__(self, multiplier, offset):
        self.multiplier = multiplier
        self.offset = offset

    def getScaledValue(self, value):
        """Returns the real applied value before the voltage devider that corresponds to a measured value of the ADS chip."""
        return self.multiplier * value + self.offset


class ADS8885:
    """
    A class used to represent the ADS8885 Chip.
    ...

    Attributes
    ----------
    pin1,pin2:  integer which represents the pinnumber of the PCAL chip to control the <br>
                -VSel1/2 pin of the corresponding TS5A3359DCUR chip for the voltage measurement <br>
                -IRngSel1/2 pin used for the current measurement <br>
    measurement ==0 voltage measurement <br>
                ==1 current measurement <br>
    """
    voltageMap = {
        1 : {
            "unit":"mV",
            "max":50
        },
        2 : {
            "unit":"mV",
            "max":500
        },
        3 : {
            "unit":"V",
            "max":5
        }
    }
    currentMap = {
        1 : {
            "unit":"uA",
            "max":500
        },
        2 : {
            "unit":"mA",
            "max":50
        }
    }


    def __init__(self, name, measurement, pinAss1, pinAss2, ioExpander, cspin, resolutionScalers, vref = 2.5):
        self.name = name
        self.vref = vref
        self.pinAss1 = pinAss1
        self.pinAss2 = pinAss2
        self.ioExpander = ioExpander
        self.resolution = 1
        self.cspin = cspin
        self.measurement = measurement
        self.autoResolution=False

        self.resolutionScalers = resolutionScalers

        if(simul == False):
            GPIO.setup(self.cspin, GPIO.OUT, initial = GPIO.LOW)
            self.ioExpander.setToOutputPinAssignment(pinAss1)
            self.ioExpander.setToOutputPinAssignment(pinAss2)
        #Voltage measurement
        if(measurement == 0):
            self.resolutionMap = self.voltageMap
        else:
            self.resolutionMap = self.currentMap





        # if (simul==False):
        #     self.spi = spidev.SpiDev()
        #     # self.spi.bits_per_word = 8
        #     self.spi.open(0,1)
        #     self.spi.max_speed_hz = 7629 #Todo tweek
        #     self.spi.mode = 0b10
        #     self.spi.cshigh = True
        #     #self.spi.no_cs = True
        #     #self.spi.lsbfirst = True
        #     GPIO.setup(self.cspin, GPIO.OUT)

    def getVoltage(self):
        """ return the voltage that is measured by the ADS chip.
        This voltage needs to be scaled up using the scaleToResolution function, to get the real applied voltage."""
        # print("getVoltage in: " + self.name)

        if(simul):
            return random.randint(0,  int(self.vref))
            # return random.randint(0,self.getMaxRange()) / 100

        data = self.getAdcValue()

        # print("Got data " + bin(data))
        #
        # st = bin(data) + (18-(len(bin(data))-2))*"0";
        #
        # print("n data : " + st,2)
        # # 0000 - 01ffff -> POS
        # # 1000 - 11fffff -> neg
        # print(st)
        # # data = 0x20000
        MSB = (int)((data & (0b1 << 17)) != 0)
        valToXor = (0x3FFFF * MSB)
        xored = (data ^ valToXor)
        val = xored + MSB

        # print(val)
        # print("xored: " + bin(xored))


        maxVal = 0x1FFFF
        # print("maxVal: " + str(maxVal))

        ratio = (val / maxVal)

        value = self.vref * ratio
        if(MSB):
            value *= -1

        # logger.debug("value: " + str(value) + "ratio: " + str(ratio))
        # print("first bit: " + str(data & (0b1 << 17)) == 0)

        return (-1) * value;

    def getVoltageFast(self):
        """ Fast implementation of the getVoltage() function """
        data = self.getAdcValue()

        MSB = (bool)((data & (0b1 << 17)) != 0)
        val = (data ^  (0x3FFFF * MSB)) + MSB

        value = self.vref * (val / 0x1FFFF)

        if(MSB == False):
                return -value
        return value

    def scaleToResolution(self, value):
        """ scales a measured value from the ADS chip to the real applied value using internal ResolutionScaler objects that are set when creating this class"""
        # print(self.name + " get scale to resolution for value : " + str(value))
        # print(self.resolution)
        # print(self.resolutionScalers[self.resolution].multiplier)
        # print(self.resolutionScalers[self.resolution].offset)
        # print("ret: " + str(self.resolutionScalers[self.resolution].getScaledValue(value)))
        return self.resolutionScalers[self.resolution].getScaledValue(value)
        # # self.calibrationMap[self.resolution]
        # return self.muliplier * value + self.offset;
        # # return value
        # # tmp = 0.0114*value**2 + 1.2688 * value + 2.0662
        # # if(self.name == "vm1"):
        # #     return value * 2.3307 - 0.1192 #* 3.133 - 40.6;
        # # elif(self.name == "vm2"):
        # #     return value * 2.3487 + 0.0375 #* 3.133 - 40.6;
        # # return value;

    def getMaxRange(self):
        """ Return the max value that can be measured in this range"""
        return self.resolutionMap[self.resolution]["max"]

    def getUnit(self):
        """ Return the unit of this measurement"""
        return self.resolutionMap[self.resolution]["unit"]

    def getName(self):
        """ Returns the name of this measurement device"""
        return self.name
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

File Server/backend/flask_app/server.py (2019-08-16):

# !/usr/bin/env python
# -*- coding: utf-8 -*-
"""Entry point for the server application."""
import threading
import json
import logging
from pylogging import HandlerType, setup_logger
import time
import os
import sys


from flask_cors import CORS
from .config import CONFIG
import traceback
from flask import request, jsonify, current_app, Flask
from flask_jwt_simple import (
    JWTManager, jwt_required, create_jwt, get_jwt_identity
)

from .http_codes import Status
from flask import make_response

from datetime import timedelta, datetime
from functools import update_wrapper


logger = logging.getLogger(__name__)
setup_logger(log_directory='./logs', file_handler_type=HandlerType.ROTATING_FILE_HANDLER, allow_console_logging = True, console_log_level  = logging.DEBUG, max_file_size_bytes = 1000000)


try:
    import RPi.GPIO as GPIO
    from pijuice import PiJuice # Import pijuice module
    import rpi_backlight as backlight
    simul = False
except ImportError:
    simul = True
    logger.error("could not import GPIO")

# import cv2
#
# cap = cv2.VideoCapture(0)

if(simul == False):
    GPIO.setmode(GPIO.BCM)


# Import used Devices, must be here because GPIO Mode has to be set first
from .Devices import varSupplies, LTCDevices, measurementDevices

SPI_MOSI = 10
SPI_MISO = 9
SPI_CLK = 11

if(simul == False):
    GPIO.setup(SPI_MOSI, GPIO.OUT, initial = GPIO.LOW)
    GPIO.setup(SPI_MISO, GPIO.OUT, initial = GPIO.LOW)
    GPIO.setup(SPI_CLK, GPIO.OUT, initial = GPIO.LOW)

mutex = threading.Lock()
# Create Flask App
app = Flask(__name__)
# Load Configuration for app. Secret key etc.
config_name = os.getenv('FLASK_CONFIGURATION', 'default')
app.config.from_object(CONFIG[config_name])

# Set Cors header. Used to accept connections from browser using XHTTP requests.
CORS(app, headers=['Content-Type'])
jwt = JWTManager(app)


 # Object to store the last measured voltage values
voltageValues = {}
voltageValuesSum = {}

#Pin Code
pinCode = app.config["PIN_CODE"]

#Polling time delay for Polling thread
pollingTimeDelay = app.config["POLLING_TIME_DELAY"]


if(not simul):
    pijuice = PiJuice(1, 0x14) # Instantiate PiJuice interface object
#init values
for dev in measurementDevices.keys():
    obj = {
        "value" : 0,
        "unit" : "",
        "max": ""
    }
    voltageValues[dev] = obj;

""" Path to config file (.json) for frontend """
CONF_FILE = os.path.join(os.path.dirname(__file__), 'conf.json')
OUTPUT_FILE = os.path.join(os.path.dirname(__file__), 'output.csv')
EXPORT_FOLDER = os.path.join(os.path.dirname(__file__), '../export/')

@jwt.jwt_data_loader
def add_claims_to_access_token(identity):
    now = datetime.utcnow()
    return {
        'exp': now + current_app.config['JWT_EXPIRES'],
        'iat': now,
        'nbf': now,
        'sub': identity,
        'roles': 'Admin'
    }


def crossdomain(origin=None, methods=None, headers=None, max_age=21600,
                attach_to_all=True, automatic_options=True):
    """Decorator function that allows crossdomain requests.
      Courtesy of
      https://blog.skyred.fi/articles/better-crossdomain-snippet-for-flask.html
    """
    if methods is not None:
        methods = ', '.join(sorted(x.upper() for x in methods))
    # use str instead of basestring if using Python 3.x
    if headers is not None and not isinstance(headers, list):
        headers = ', '.join(x.upper() for x in headers)
    # use str instead of basestring if using Python 3.x
    if not isinstance(origin, list):
        origin = ', '.join(origin)
    if isinstance(max_age, timedelta):
        max_age = max_age.total_seconds()

    def get_methods():
        """ Determines which methods are allowed
        """
        if methods is not None:
            return methods

        options_resp = current_app.make_default_options_response()
        return options_resp.headers['allow']

    def decorator(f):
        """The decorator function
        """
        def wrapped_function(*args, **kwargs):
            """Caries out the actual cross domain code
            """
            if automatic_options and request.method == 'OPTIONS':
                resp = current_app.make_default_options_response()
            else:
                resp = make_response(f(*args, **kwargs))
            if not attach_to_all and request.method != 'OPTIONS':
                return resp

            h = resp.headers
            h['Access-Control-Allow-Origin'] = origin
            h['Access-Control-Allow-Methods'] = get_methods()
            h['Access-Control-Max-Age'] = str(max_age)
            h['Access-Control-Allow-Credentials'] = 'true'
            h['Access-Control-Allow-Headers'] = \
                "Origin, X-Requested-With, Content-Type, Accept, Authorization"
            if headers is not None:
                h['Access-Control-Allow-Headers'] = headers
            return resp

        f.provide_automatic_options = False
        return update_wrapper(wrapped_function, f)
    return decorator



#-------------------------------------------------------------------------------
#                       BEGIN API Functions
#-------------------------------------------------------------------------------
@app.route('/api/storeconfig', methods=['POST', 'OPTIONS'])
@crossdomain(origin = '*')
@jwt_required
def storeConfig():
    """
        ### API Path   `/api/storeconfig`
        ### Request Type: `POST`
        Stores the given JSON Object in the Config file specifed by the  CONF_FILE variable.
        If the JWT Cookie is not set, this method will return Status Code 401 UNAUTHORIZED.
        Return Status Code 500 if the file could not be opened.
    """
    try:
        storeConfigObject(request.get_json())
    except IOError as e:
        error = "I/O Error " + str(e.errno) + " " + str(e.strerror)
        logger.error(error)
        return error , Status.HTTP_SERVER_ERROR;

    return "OK", Status.HTTP_OK_BASIC


@app.route('/api/loadconfig', methods=['GET', 'OPTIONS'])
@crossdomain(origin = '*')
def loadConfig():
    """
    ### API Path   `/api/loadconfig`
    ### Request Type: `GET`
    Loads the configuration specified in the CONF_FILE file.
    Returns a JSON Object with all Configurations that are defined."""
    try:
        with open(CONF_FILE,'r') as file:
            return file.read(), Status.HTTP_OK_BASIC
    except IOError as e:
        error = "I/O Error " + str(e.errno) + " " + str(e.strerror)
        logger.error(error)
        return error, Status.HTTP_SERVER_ERROR;

    return "Unknown Error", Status.HTTP_SERVER_ERROR;
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
